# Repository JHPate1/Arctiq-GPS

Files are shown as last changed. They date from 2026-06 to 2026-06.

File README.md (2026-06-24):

GPS Banner
# Arctiq-GPS
A mainboard PCB design for my custom handheld navigation device.
(first time making a PCB and it all looks good so far!)

## What does it do?
This might seem vague if you don't know much about the project, so I'll try to explain everything here, along with who I am and my background.
PCB Image
## Who I am
I'm Jyot Patel, a 14-year-old living in the United States. I recently moved from Canada, where I was raised my entire life (born in India though). I like tinkering and making software projects in my free time, though I never really used GitHub that often. Git CLI just wasn't for me.

## What is this project?
This is the core foundation of my handheld device. It contains the power circuitry and the main GPS module that handles everything. At the heart of it sits an RPI CM4 module, which controls everything and runs the main OS I plan on flashing to the SD card.

## Why did I take on such an ambitious project for my first PCB?
Honestly, it was kind of a bad idea for a first PCB, but I do have experience with real hardware. It was more of a motivational thing: when you want to give up, you realize how much you've already put into the project, and that pushes you to keep going. This was my 4th revision of the board, so as you can see, it took me a while to get here.

## The routing looks ugly
I can admit the routing is terrible, but I checked it for the specific purpose and this will work just fine. I wasn't planning on making a Mona Lisa on a PCB. I just needed a functional board that won't explode after 3 years.

## Known Errors

Any DRC or ERC errors are left on purpose, KiCad was being a pain in the butt during import and export. I couldn't connect some traces, and there are a few schematic/footprint mixups. Take the PCB as the source of truth only!!!
If you spot anything else, feel free to open an issue.

### Special Thanks!
Special thanks to Hack Club Stardance for motivating me on this project. Without your help, I wouldn't have done it!

Thanks to https://github.com/ShawnHymel/rpi-cm4-carrier-template for providing me with the CM4 Carrier template!

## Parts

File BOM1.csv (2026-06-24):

# | Designator | Footprint | Qty | Designation | Recommended Spec | Digi-Key Part # | Unit Price | Ext Price
1 | C1 | C_0603_1608Metric | 1 | 4.7µF | 4.7µF, X5R/X7R, ≥10V | Search Caps | $0.05 | $0.05
2 | C2 | C_0603_1608Metric | 1 | 22µF | 22µF, X5R/X7R, ≥10V | Search Caps | $0.05 | $0.05
3 | C3, C6, C19, C21, C22 | C_0603_1608Metric | 5 | 100nF | 100nF, X7R, ≥10V | Search Caps | $0.05 | $0.25
4 | C4 | C_0603_1608Metric | 1 | 10µF | 10µF, X5R/X7R, ≥6.3V | Search Caps | $0.05 | $0.05
5 | C5 | C_0603_1608Metric | 1 | 33pF | 33pF, C0G/NP0, ≥25V | Search Caps | $0.05 | $0.05
6 | C7 | C_0603_1608Metric | 1 | 10µF | 10µF, X5R/X7R, ≥6.3V | Search Caps | $0.05 | $0.05
7 | C8 | C_0603_1608Metric | 1 | 20µF | 20µF, X5R/X7R, ≥6.3V | Search Caps | $0.05 | $0.05
8 | C9 | C_0603_1608Metric | 1 | 1µF | 1µF, X7R, ≥10V | Search Caps | $0.05 | $0.05
9 | C10, C15, C17 | C_0603_1608Metric | 3 | 10µF | 10µF, X5R/X7R, ≥6.3V | Search Caps | $0.05 | $0.15
10 | C11, C12, C32, C33, C35, C36, C37 | C_0805_2012Metric | 7 | 22µF | 22µF, X5R/X7R, ≥10V | Search Caps | $0.05 | $0.35
11 | C13, C14, C16, C25, C31 | C_0603_1608Metric | 5 | 0.1µF | 0.1µF, X7R, ≥16V | Search Caps | $0.05 | $0.25
12 | C18 | C_0603_1608Metric | 1 | 1.0µF | 1.0µF, X7R, ≥6.3V | Search Caps | $0.05 | $0.05
13 | C20 | C_0603_1608Metric | 1 | 47µF | 47µF, X5R/X7R, ≥6.3V min; 10V preferred | Search Caps | $0.05 | $0.05
14 | C23 | C_0603_1608Metric | 1 | 10nF | 10nF, C0G/NP0, ≥25V | Search Caps | $0.05 | $0.05
15 | C24 | C_0603_1608Metric | 1 | 10pF | 10pF, C0G/NP0, ≥25V | Search Caps | $0.05 | $0.05
16 | C26 | C_0603_1608Metric | 1 | 22µF | 22µF, X5R/X7R, ≥6.3V | Search Caps | $0.05 | $0.05
17 | C27 | C_0603_1608Metric | 1 | 2.2µF | 2.2µF, X7R, ≥10V | Search Caps | $0.05 | $0.05
18 | C28 | C_0805_2012Metric | 1 | 68nF | 68nF, X7R, ≥10V | Search Caps | $0.05 | $0.05
19 | C29 | C_0603_1608Metric | 1 | 4.7nF | 4.7nF, X7R/C0G, ≥10V | Search Caps | $0.05 | $0.05
20 | C30 | C_0603_1608Metric | 1 | 47pF | 47pF, C0G/NP0, ≥25V | Search Caps | $0.05 | $0.05
21 | C34 | C_0603_1608Metric | 1 | 47µF | 47µF, X5R/X7R, ≥6.3V min; 10V preferred | Search Caps | $0.05 | $0.05
22 | D1 | LED_0402_1005Metric | 1 | LED |  | Search LEDs | $0.15 | $0.15
23 | D2 | LED_0402_1005Metric | 1 | DEBUG |  | Search LEDs | $0.15 | $0.15
24 | J1 | USB_C_Receptacle_GCT_USB4085 | 1 | USB-C Receptacle |  | 2073-USB4085-GF-ACT-ND | $0.89 | $0.89
25 | J2 | SolderWire-0.127sqmm_1x02_P3.7mm | 1 | Conn_01x02_Socket |  | Search Connectors | $0.50 | $0.50
26 | J3 | U.FL_Hirose_U.FL-R-SMT-1_Vertical | 1 | U.FL Coaxial Connector |  | H11891CT-ND | $1.29 | $1.29
27 | J4 | microSD_HC_Wuerth_693072010801 | 1 | microSD Card Holder |  | 732-693072010801-1-ND | $3.41 | $3.41
28 | J5 | JST_NV_B04P-NV_1x04_P5.00mm_Vertical | 1 | Conn_01x04_Socket |  | Search Connectors | $0.50 | $0.50
29 | J6 | CON_522711569_MOL | 1 | 522711569 |  | Search Connectors | $0.50 | $0.50
30 | J7 | PinHeader_1x02_P2.54mm_Vertical | 1 | 01x02 Pin Header |  | Search Connectors | $0.50 | $0.50
31 | L1 | L_1210_3225Metric | 1 | 1.5µH | 1.5µH shielded power inductor, Isat ≥12A, low DCR | Search Inductors | $0.80 | $0.80
32 | L2 | L_0402_1005Metric | 1 | 27nH | 27nH RF inductor/matching part | Search Inductors | $0.80 | $0.80
33 | L3 | L_0402_1005Metric | 1 | 1µH | 1µH power inductor, Isat ≥6A (0402 unsuitable for BQ25895 power stage) | Search Inductors | $0.80 | $0.80
34 | L4 | L_0603_1608Metric | 1 | 2.2µH | 2.2µH shielded power inductor, Isat ≥3A, low DCR | Search Inductors | $0.80 | $0.80
35 | MK1 | Knowles_SPH0645LM4H-6_3.5x2.65mm | 1 | SPH0645LM4H | MEMS Microphone | 6017-SPH0645LM4H-BCT-ND | $3.44 | $3.44
36 | Module1 | Raspberry-Pi-4-Compute-Module | 1 | CM4 Compute Module | Raspberry Pi Compute Module 4 (SC0667) | 2648-SC0667-ND | $63.23 | $63.23
37 | R1, R2 | R_0603_1608Metric | 2 | 5.1k |  | Search Resistors | $0.01 | $0.02
38 | R3, R10, R23 | R_0603_1608Metric | 3 | 10K |  | Search Resistors | $0.01 | $0.03
39 | R4 | R_0603_1608Metric | 1 | 200 | ILIM resistor | Search Resistors | $0.01 | $0.01
40 | R5 | R_0603_1608Metric | 1 | 10kΩ |  | Search Resistors | $0.01 | $0.01
41 | R6 | R_0603_1608Metric | 1 | 12K 1% |  | Search Resistors | $0.01 | $0.01
42 | R7, R8, R21, R22 | R_0603_1608Metric | 4 | 4.7k |  | Search Resistors | $0.01 | $0.04
43 | R9, R14, R15 | R_0603_1608Metric | 3 | 10k |  | Search Resistors | $0.01 | $0.03
44 | R11, R24, R27, R28 | R_0603_1608Metric | 4 | 100k |  | Search Resistors | $0.01 | $0.04
45 | R12, R17, R25 | R_0603_1608Metric | 3 | 100K |  | Search Resistors | $0.01 | $0.03
46 | R13 | R_0603_1608Metric | 1 | 2.2k |  | Search Resistors | $0.01 | $0.01
47 | R16 | R_0603_1608Metric | 1 | 100 |  | Search Resistors | $0.01 | $0.01
48 | R18 | R_0603_1608Metric | 1 | 15k |  | Search Resistors | $0.01 | $0.01
49 | R19 | R_0603_1608Metric | 1 | 1K |  | Search Resistors | $0.01 | $0.01
50 | R20 | R_0603_1608Metric | 1 | 316k |  | Search Resistors | $0.01 | $0.01
51 | R26 | R_0603_1608Metric | 1 | 453k |  | Search Resistors | $0.01 | $0.01
52 | SW2 | Panasonic_EVQPUJ_EVQPUA | 1 | Push Button Switch | Shielded tactile switch | P8029SCT-ND | $0.60 | $0.60
53 | TH1 | R_0201_0603Metric | 1 | 10K | Thermistor | Search Resistors | $0.01 | $0.01
54 | U1 | Texas_RTW_WQFN-24-1EP_4x4mm | 1 | BQ25895RTW | Battery Buck-Boost Charger | 296-44345-1-ND | $3.29 | $3.29
55 | U2 | ublox_NEO | 1 | NEO-M9N | GNSS Receiver Module | 672-NEO-M9N-00B-ND | $14.69 | $14.69
56 | U3 | TSOT-23-5_RIT | 1 | RT9742GGJ5 | Power Load Switch | 1028-1436-1-ND | $0.92 | $0.92
57 | U4 | DRL0006A | 1 | TPS6282533DMQR | Buck Converter 3.3V 2A | 296-TPS6282533DMQRCT-ND | $1.25 | $1.25
58 | U5 | TQFN-16-1EP_3x3mm | 1 | MAX98357A | Class D Audio Amplifier | MAX98357AETE+TCT-ND | $3.73 | $3.73
59 | U6 | SOT-23-6 | 1 | USBLC6-2SC6 | USB ESD Protection | 497-11882-1-ND | $0.67 | $0.67
60 | U7 | 21-0168E_T822-3_MXM | 1 | MAX17048G+T10 | Fuel Gauge IC | MAX17048G+T10CT-ND | $3.62 | $3.62
61 | U8 | RHL0020A | 1 | TPS61088RHLR | Boost Converter 10A | 296-42129-1-ND | $2.74 | $2.74
62 | U9 | 21-0114C_MXM | 1 | MAX16054AZT+ | Pushbutton On/Off Controller | MAX16054AZT+TCT-ND | $3.71 | $3.71
63 | NOB | 4 PIN POGO MAG | 1 | 4-Pin Pogo Magnetic Connector |  | Amazon: B0GJPCX49H | $9.99 | $9.99
64 | NOB | 5 INCH DISPLAY, CAPACITIVE TOUCH, DSI | 1 | 5" DSI Capacitive Touch Display | Waveshare 800×480 | Amazon: B08H23KB1G | $46.00 | $46.00
65 | NOB | Active GNSS ANT | 1 | Active GNSS Antenna |  | AliExpress | $8.00 | $8.00
66 | NOB | 5000MAH Battery | 2 | 5000mAh LiPo Battery | 3.7V with JST PH2.0 connector | Amazon: B0GL1MH5YT | $13.00 | $26.00
67 | NOB | 128GB SD | 1 | 128GB microSD Card | Kingston Canvas Select Plus | Amazon: B0FCZTYSN6 | $23.99 | $23.99
68 | NOB | ABS/RESIN ENCLOSURE | 1 | ABS/Resin Enclosure | Custom enclosure | PCBWAY (custom) | $25.00 | $25.00
69 | NOB | SPEAKER | 1 | Speaker |  | AliExpress | $5.00 | $5.00
70 | NOB | PCB + SHIPPING | 1 | PCB Fabrication & Shipping | PCB fabrication + component shipping | PCBWAY | $75.00 | $75.00
 |  | TOTAL | 100 |  |  |  |  | $334.10

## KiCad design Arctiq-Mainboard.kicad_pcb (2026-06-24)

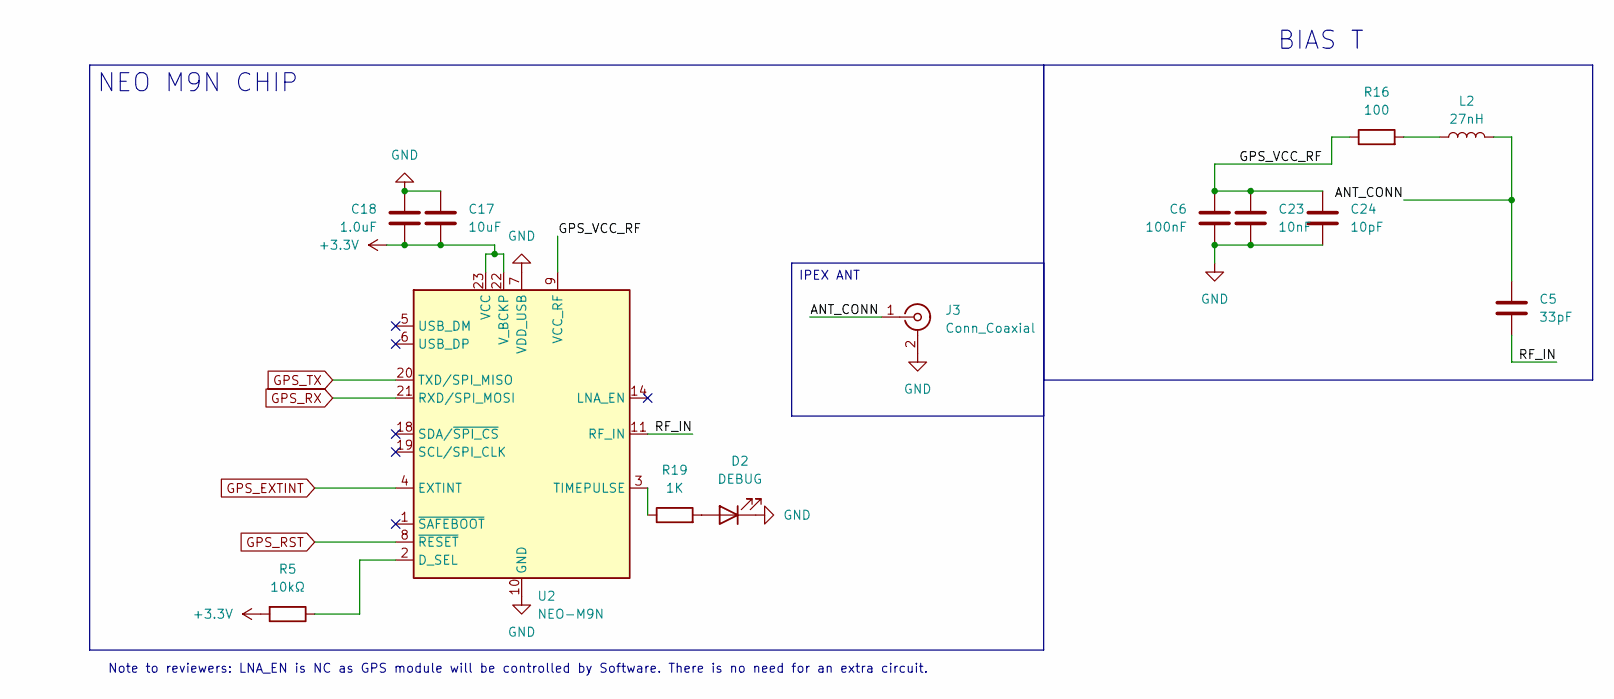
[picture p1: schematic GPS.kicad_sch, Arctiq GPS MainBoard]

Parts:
C5: 33pF; C_0603_1608Metric
C6: 100nF; C_0603_1608Metric
C17: 10uF; C_0603_1608Metric
C18: 1.0uF; C_0603_1608Metric
C23: 10nF; C_0603_1608Metric
C24: 10pF; C_0603_1608Metric
D2: DEBUG; LED_0402_1005Metric
J3: Conn_Coaxial; U.FL_Hirose_U.FL-R-SMT-1_Vertical
L2: 27nH; L_0402_1005Metric
R5: 10kΩ; R_0603_1608Metric
R16: 100; R_0603_1608Metric
R19: 1K; R_0603_1608Metric
U2: NEO-M9N; ublox_NEO

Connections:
+3.3V: C17.2, C18.2, R5.2, U2.22 (V_BCKP), U2.23 (VCC); also elsewhere on the board
/GPS Module/ANT_CONN: C5.2, J3.1 (In), L2.2
/GPS Module/GPS_VCC_RF: C6.2, C23.2, C24.2, R16.1, U2.9 (VCC_RF)
/GPS Module/RF_IN: C5.1, U2.11 (RF_IN)
GPS_EXTINT: U2.4 (EXTINT); also elsewhere on the board
GPS_RST: U2.8 (~RESET); also elsewhere on the board
GPS_RX: U2.21 (RXD/SPI_MOSI); also elsewhere on the board
GPS_TX: U2.20 (TXD/SPI_MISO); also elsewhere on the board
unnamed: D2.2 (A), R19.2
unnamed: L2.1, R16.2
unnamed: R5.1, U2.2 (D_SEL)
unnamed: R19.1, U2.3 (TIMEPULSE)

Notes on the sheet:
Note to reviewers: LNA_EN is NC as GPS module will be controlled by Software. There is no need for an extra circuit.
BIAS T
IPEX ANT
NEO M9N CHIP

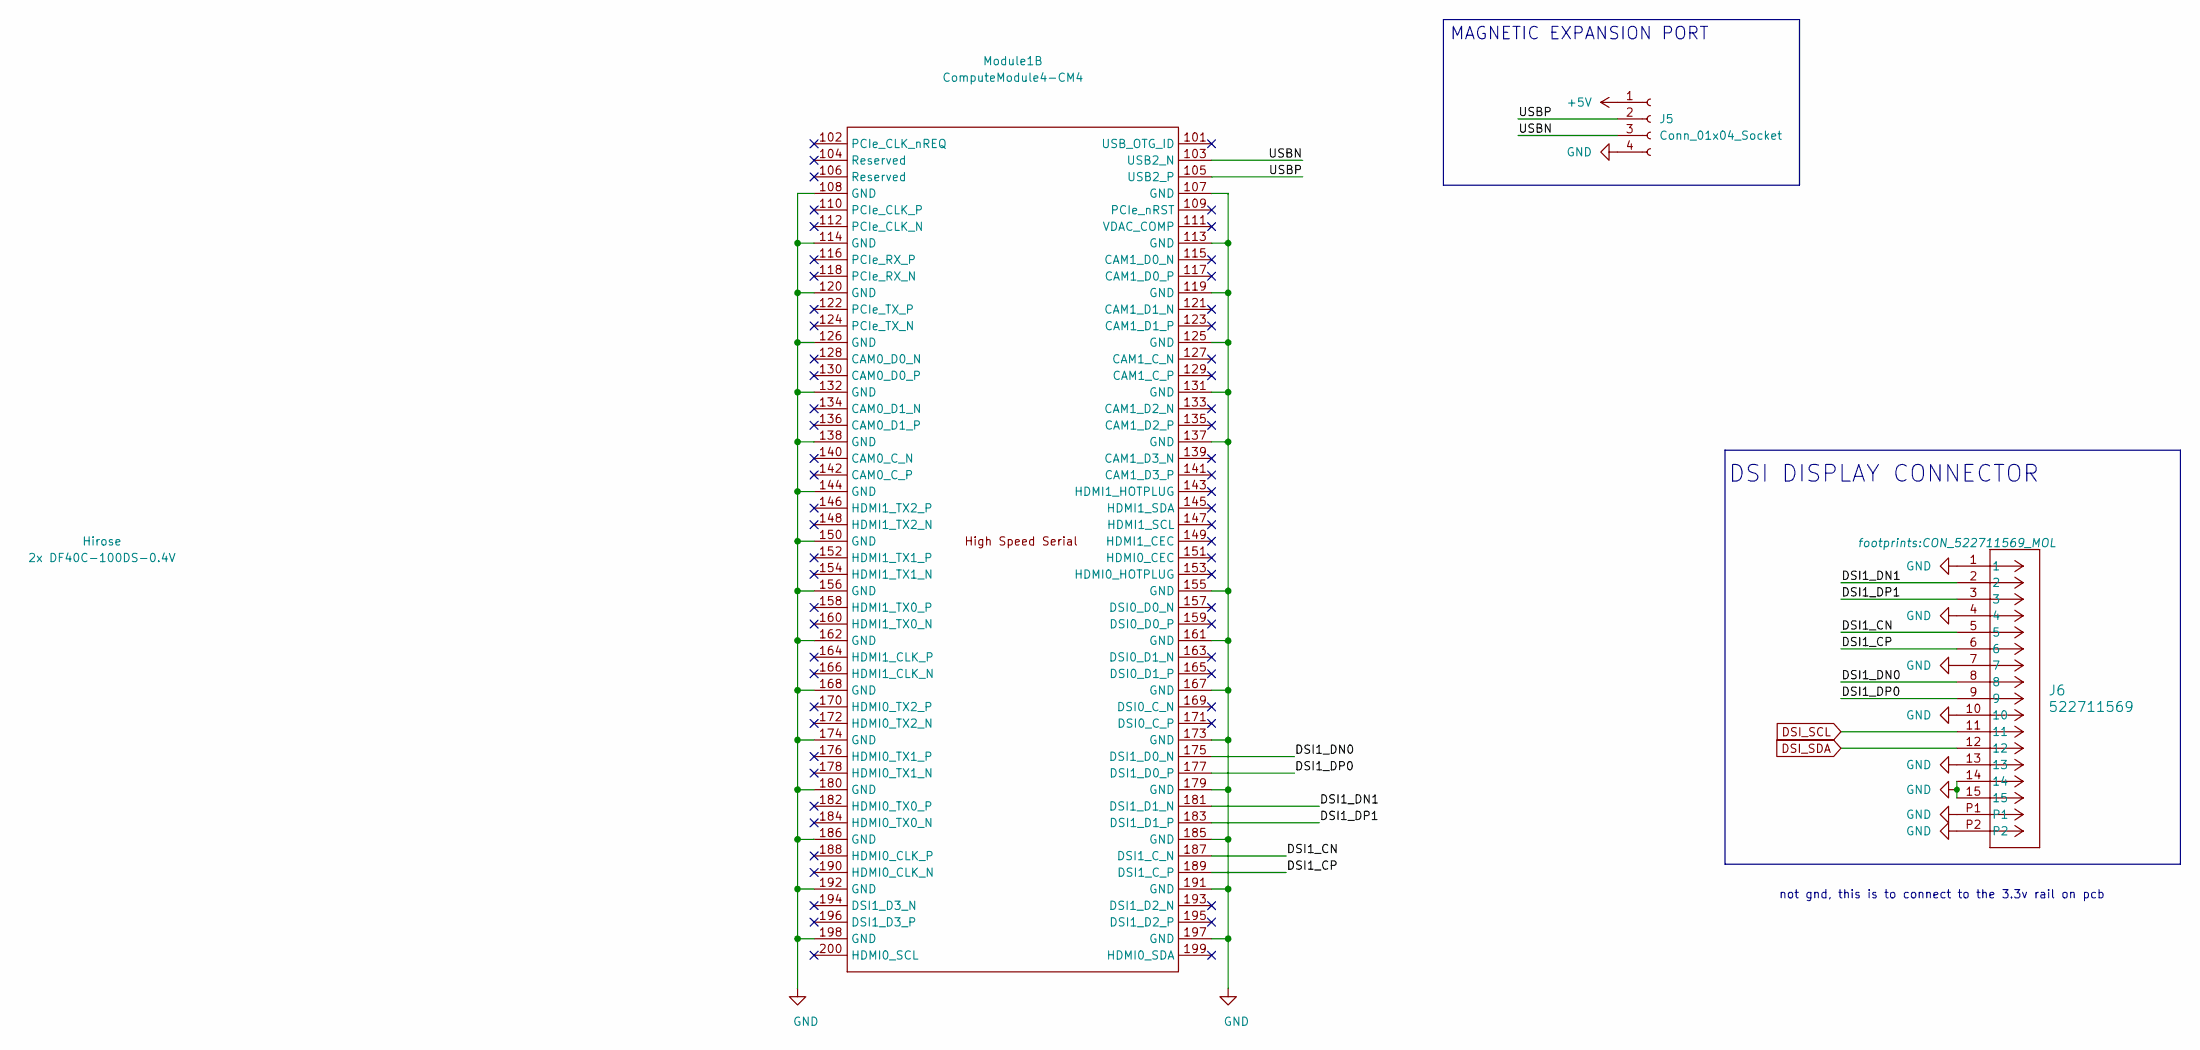
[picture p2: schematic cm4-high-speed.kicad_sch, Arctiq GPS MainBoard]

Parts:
J5: Conn_01x04_Socket; JST_NV_B04P-NV_1x04_P5.00mm_Vertical
J6: 522711569; CON_522711569_MOL
Module1: ComputeModule4-CM4; CONN100_DF40C-100DP-0.4V51_HIR; MPN 2x DF40C-100DS-0.4V; Digi-Key_PN 2x H11615CT-ND

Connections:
+5V: J5.1; also elsewhere on the board
/CM4 High Speed/DSI1_CN: J6.5, Module1.187 (DSI1_C_N)
/CM4 High Speed/DSI1_CP: J6.6, Module1.189 (DSI1_C_P)
/CM4 High Speed/DSI1_DN0: J6.8, Module1.175 (DSI1_D0_N)
/CM4 High Speed/DSI1_DN1: J6.2, Module1.181 (DSI1_D1_N)
/CM4 High Speed/DSI1_DP0: J6.9, Module1.177 (DSI1_D0_P)
/CM4 High Speed/DSI1_DP1: J6.3, Module1.183 (DSI1_D1_P)
/CM4 High Speed/USBN: J5.3, Module1.103 (USB2_N)
/CM4 High Speed/USBP: J5.2, Module1.105 (USB2_P)
DSI_SCL: J6.11; also elsewhere on the board
DSI_SDA: J6.12; also elsewhere on the board

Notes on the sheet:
not gnd, this is to connect to the 3.3v rail on pcb
DSI DISPLAY CONNECTOR
MAGNETIC EXPANSION PORT

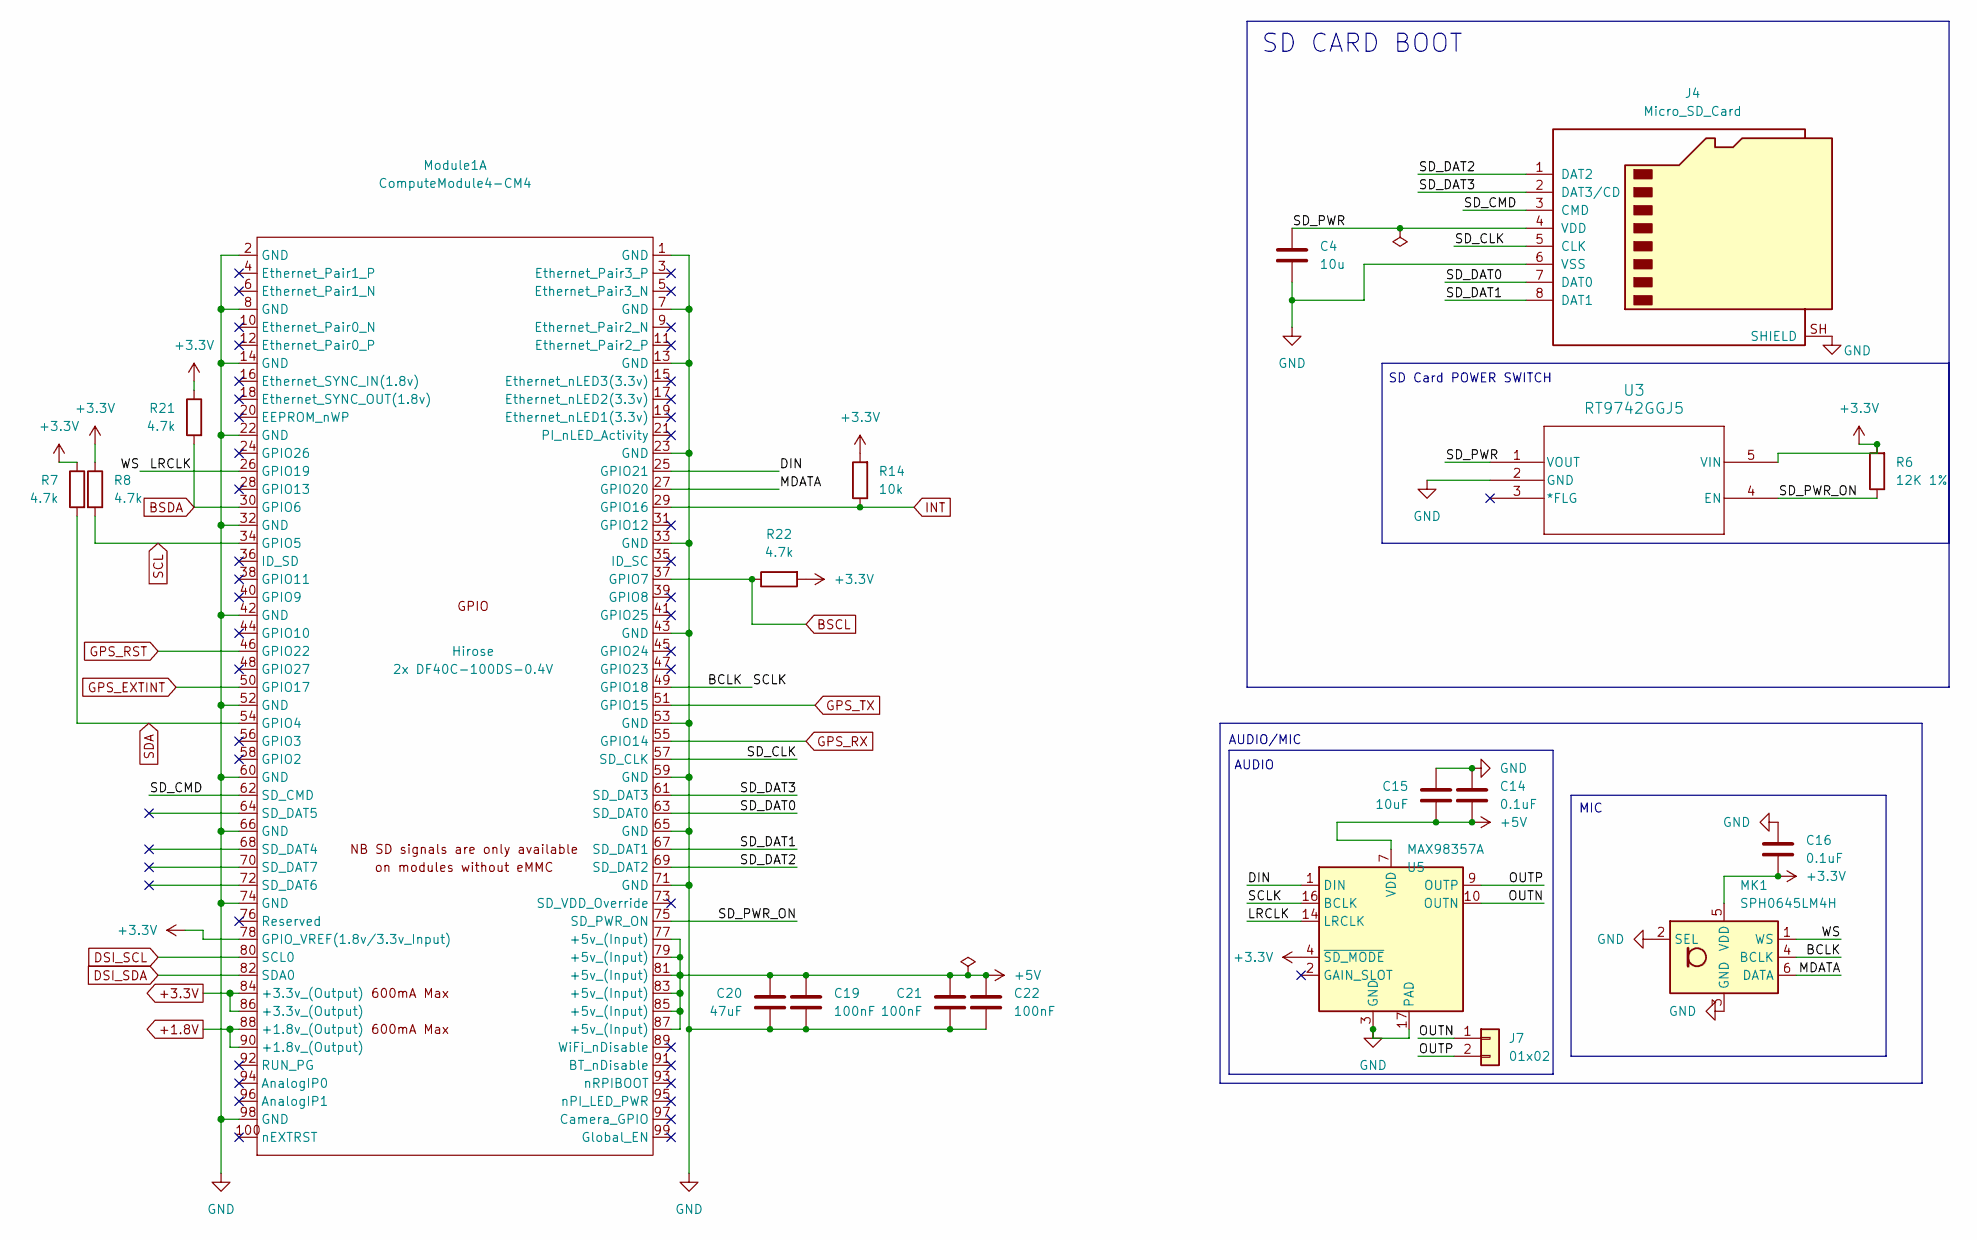
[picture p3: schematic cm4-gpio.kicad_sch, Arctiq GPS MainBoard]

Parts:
C4: 10u; C_0603_1608Metric
C14, C16: 0.1uF; C_0603_1608Metric
C15: 10uF; C_0603_1608Metric
C19, C21, C22: 100nF; C_0603_1608Metric
C20: 47uF; C_0603_1608Metric
J4: Micro_SD_Card; microSD_HC_Wuerth_693072010801
J7: 01x02; PinHeader_1x02_P2.54mm_Vertical
MK1: SPH0645LM4H; Knowles_SPH0645LM4H-6_3.5x2.65mm
Module1: ComputeModule4-CM4; CONN100_DF40C-100DP-0.4V51_HIR; MPN 2x DF40C-100DS-0.4V; Digi-Key_PN 2x H11615CT-ND
R6: 12K 1%; R_0603_1608Metric
R7, R8, R21, R22: 4.7k; R_0603_1608Metric
R14: 10k; R_0603_1608Metric
U3: RT9742GGJ5; TSOT-23-5_RIT
U5: MAX98357A; TQFN-16-1EP_3x3mm_P0.5mm_EP1.23x1.23mm

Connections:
+1.8V: Module1.88 (+1.8v_(Output)), Module1.90 (+1.8v_(Output))
+3.3V: C16.2, MK1.5 (VDD), Module1.78 (GPIO_VREF(1.8v/3.3v_Input)), Module1.84 (+3.3v_(Output)), Module1.86 (+3.3v_(Output)), R6.2, R7.1, R8.1, R14.2, R21.1, R22.2, U3.5 (VIN), U5.4 (~SD_MODE); also elsewhere on the board
+5V: C14.2, C15.2, C19.1, C20.2, C21.2, C22.1, Module1.77 (+5v_(Input)), Module1.79 (+5v_(Input)), Module1.81 (+5v_(Input)), Module1.83 (+5v_(Input)), Module1.85 (+5v_(Input)), Module1.87 (+5v_(Input)), U5.7 (VDD), U5.8 (VDD); also elsewhere on the board
/CM4 GPIO/BCLK: MK1.4 (BCLK), Module1.49 (GPIO18), U5.16 (BCLK)
/CM4 GPIO/DIN: Module1.25 (GPIO21), U5.1 (DIN)
/CM4 GPIO/LRCLK: MK1.1 (WS), Module1.26 (GPIO19), U5.14 (LRCLK)
/CM4 GPIO/MDATA: MK1.6 (DATA), Module1.27 (GPIO20)
/CM4 GPIO/OUTN: J7.1, U5.10 (OUTN)
/CM4 GPIO/OUTP: J7.2, U5.9 (OUTP)
/CM4 GPIO/SD_CLK: J4.5 (CLK), Module1.57 (SD_CLK)
/CM4 GPIO/SD_CMD: J4.3 (CMD), Module1.62 (SD_CMD)
/CM4 GPIO/SD_DAT0: J4.7 (DAT0), Module1.63 (SD_DAT0)
/CM4 GPIO/SD_DAT1: J4.8 (DAT1), Module1.67 (SD_DAT1)
/CM4 GPIO/SD_DAT2: J4.1 (DAT2), Module1.69 (SD_DAT2)
/CM4 GPIO/SD_DAT3: J4.2 (DAT3/CD), Module1.61 (SD_DAT3)
/CM4 GPIO/SD_PWR: C4.1, J4.4 (VDD), U3.1 (VOUT)
/CM4 GPIO/SD_PWR_ON: Module1.75 (SD_PWR_ON), R6.1, U3.4 (EN)
BSCL: Module1.37 (GPIO7), R22.1; also elsewhere on the board
BSDA: Module1.30 (GPIO6), R21.2; also elsewhere on the board
DSI_SCL: Module1.80 (SCL0); also elsewhere on the board
DSI_SDA: Module1.82 (SDA0); also elsewhere on the board
GPS_EXTINT: Module1.50 (GPIO17); also elsewhere on the board
GPS_RST: Module1.46 (GPIO22); also elsewhere on the board
GPS_RX: Module1.55 (GPIO14); also elsewhere on the board
GPS_TX: Module1.51 (GPIO15); also elsewhere on the board
INT: Module1.29 (GPIO16), R14.1; also elsewhere on the board
SCL: Module1.34 (GPIO5), R8.2; also elsewhere on the board
SDA: Module1.54 (GPIO4), R7.2; also elsewhere on the board

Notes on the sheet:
AUDIO
MIC
SD CARD BOOT
AUDIO/MIC
SD Card POWER SWITCH

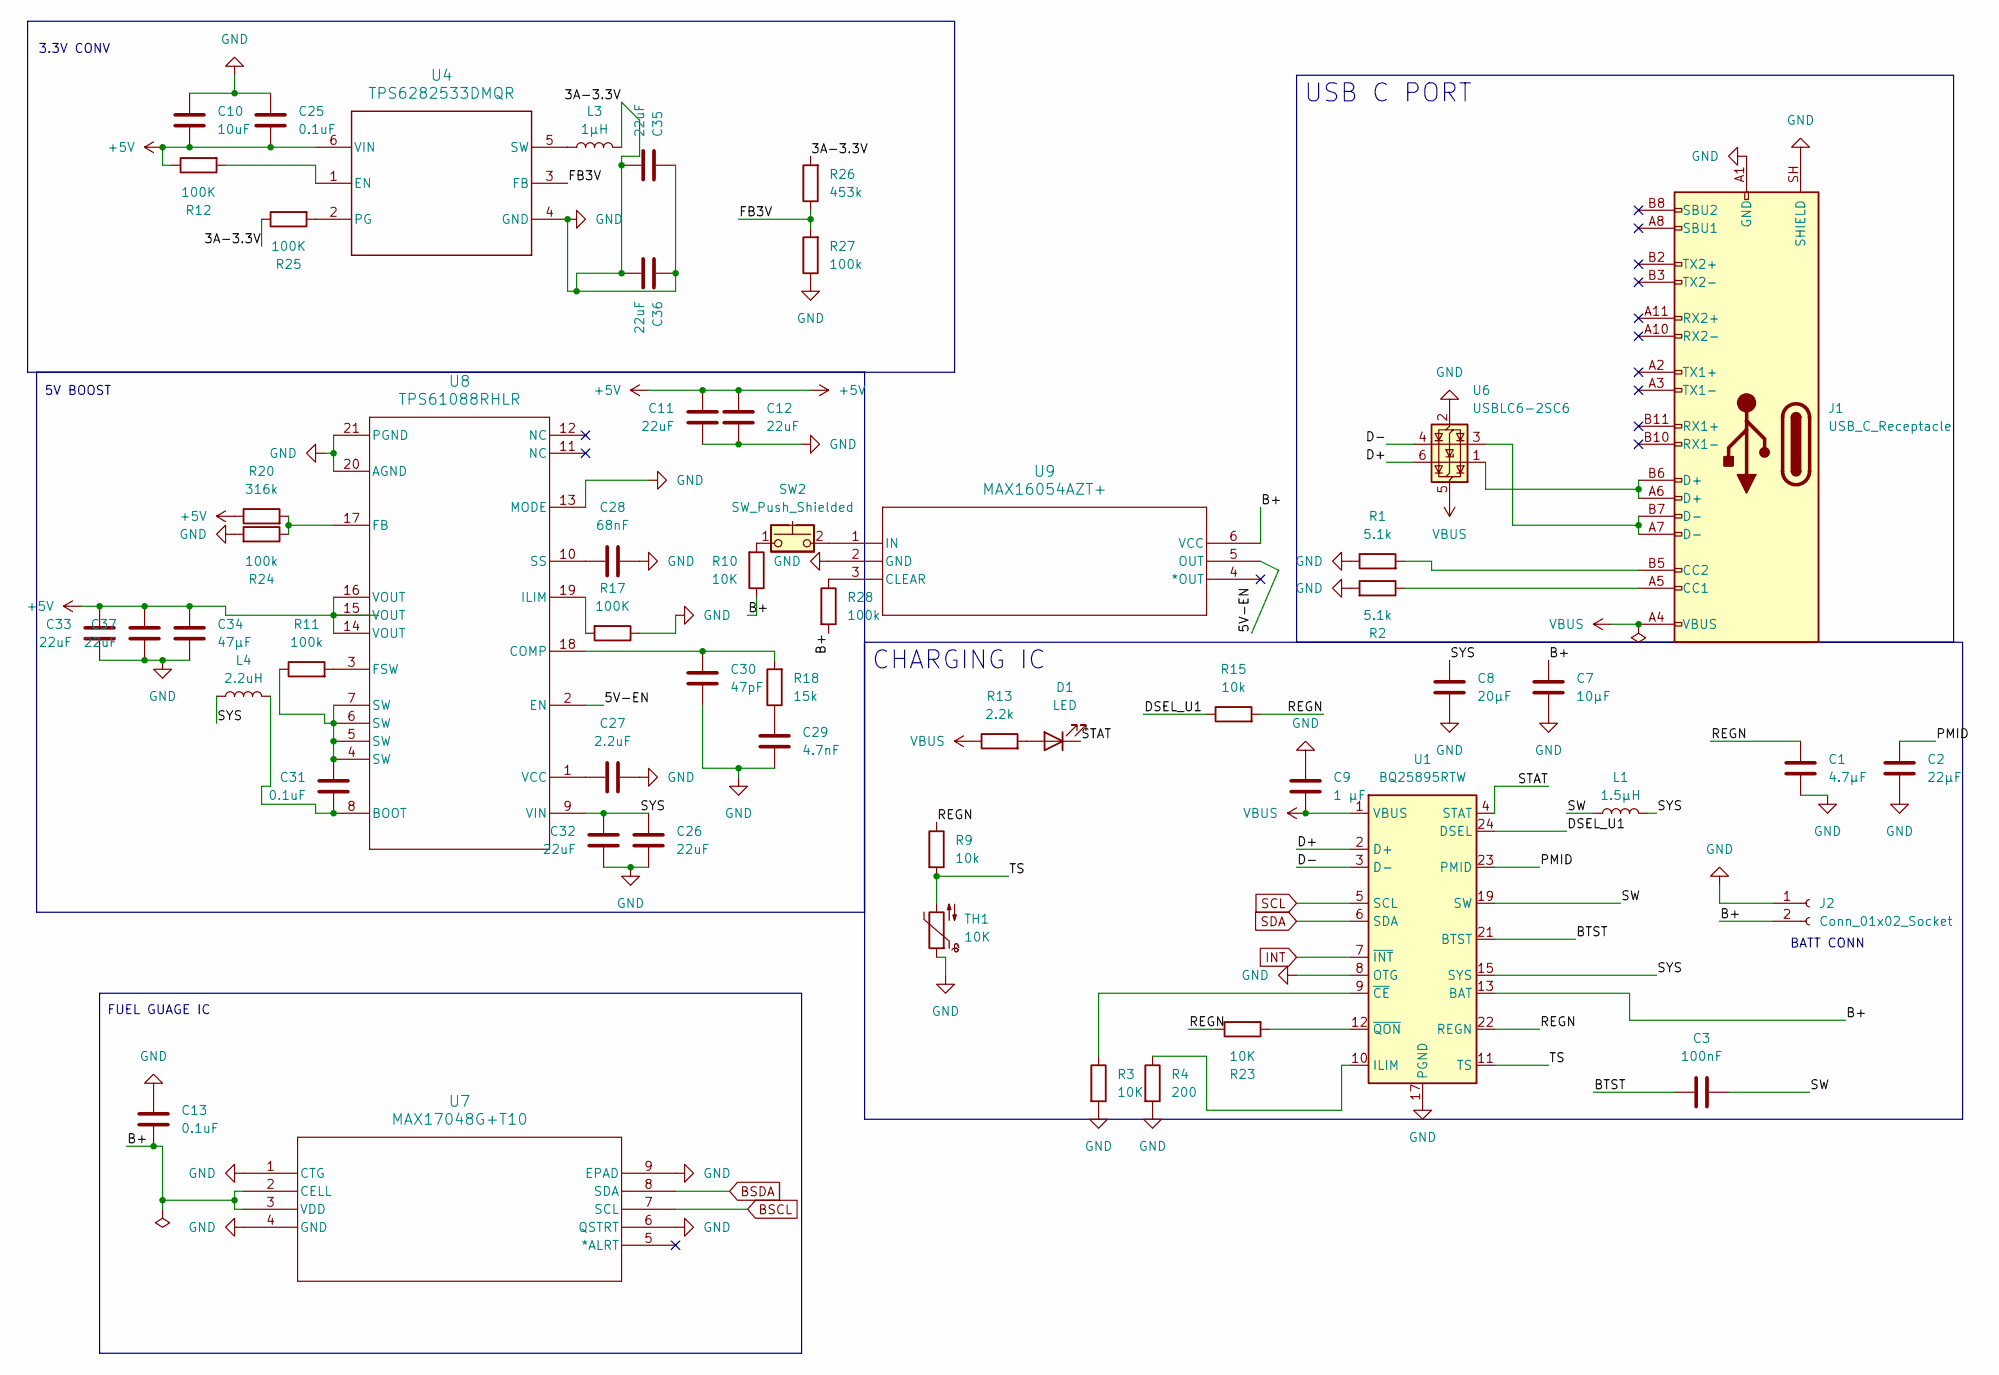
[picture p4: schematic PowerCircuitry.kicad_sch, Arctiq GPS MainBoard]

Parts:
C1: 4.7µF; C_0603_1608Metric
C2: 22µF; C_0603_1608Metric
C3: 100nF; C_0603_1608Metric
C7: 10µF; C_0603_1608Metric
C8: 20µF; C_0603_1608Metric
C9: 1 µF; C_0603_1608Metric
C10: 10uF; C_0603_1608Metric
C11, C12, C32, C33, C35, C36, C37: 22uF; C_0805_2012Metric
C13, C25, C31: 0.1uF; C_0603_1608Metric
C26: 22uF; C_0603_1608Metric
C27: 2.2uF; C_0603_1608Metric
C28: 68nF; C_0805_2012Metric
C29: 4.7nF; C_0603_1608Metric
C30: 47pF; C_0603_1608Metric
C34: 47µF; C_0603_1608Metric
D1: LED; LED_0402_1005Metric
J1: USB_C_Receptacle; USB_C_Receptacle_GCT_USB4085
J2: Conn_01x02_Socket; SolderWire-0.127sqmm_1x02_P3.7mm_D0.48mm_OD1mm
L1: 1.5µH; L_1210_3225Metric
L3: 1µH; L_0402_1005Metric
L4: 2.2uH; L_0603_1608Metric
R1, R2: 5.1k; R_0603_1608Metric
R3, R10, R23: 10K; R_0603_1608Metric
R4: 200; R_0603_1608Metric
R9, R15: 10k; R_0603_1608Metric
R11, R24, R27, R28: 100k; R_0603_1608Metric
R12, R17, R25: 100K; R_0603_1608Metric
R13: 2.2k; R_0603_1608Metric
R18: 15k; R_0603_1608Metric
R20: 316k; R_0603_1608Metric
R26: 453k; R_0603_1608Metric
SW2: SW_Push_Shielded; Panasonic_EVQPUJ_EVQPUA
TH1: 10K; R_0201_0603Metric
U1: BQ25895RTW; Texas_RTW_WQFN-24-1EP_4x4mm_P0.5mm_EP2.7x2.7mm_ThermalVias
U4: TPS6282533DMQR; DRL0006A
U6: USBLC6-2SC6; SOT-23-6
U7: MAX17048G+T10; 21-0168E_T822-3_MXM
U8: TPS61088RHLR; RHL0020A
U9: MAX16054AZT+; 21-0114C_MXM

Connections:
+5V: C10.2, C11.1, C12.1, C25.2, C33.2, C34.1, C37.2, R12.1, R20.1, U4.6 (VIN), U8.14 (VOUT), U8.15 (VOUT), U8.16 (VOUT); also elsewhere on the board
/Power Circuitry/5V-EN: U8.2 (EN), U9.5 (OUT)
/Power Circuitry/B+: C7.2, C13.2, J2.2, R10.1, R28.2, U1.13 (BAT), U1.14 (BAT), U7.2 (CELL), U7.3 (VDD), U9.6 (VCC)
/Power Circuitry/BTST: C3.2, U1.21 (BTST)
/Power Circuitry/D+: U1.2 (D+), U6.6 (I/O1)
/Power Circuitry/D-: U1.3 (D-), U6.4 (I/O2)
/Power Circuitry/DSEL_U1: R15.1, U1.24 (DSEL)
/Power Circuitry/FB3V: R26.1, R27.2, U4.3 (FB)
/Power Circuitry/PMID: C2.1, U1.23 (PMID)
/Power Circuitry/REGN: C1.2, R9.1, R15.2, R23.1, U1.22 (REGN)
/Power Circuitry/STAT: D1.1 (K), U1.4 (STAT)
/Power Circuitry/SW: C3.1, L1.1, U1.19 (SW), U1.20 (SW)
/Power Circuitry/SYS: C8.2, C26.1, C32.2, L1.2, L4.1, U1.15 (SYS), U1.16 (SYS), U8.9 (VIN)
/Power Circuitry/TS: R9.2, TH1.2, U1.11 (TS)
BSCL: U7.7 (SCL); also elsewhere on the board
BSDA: U7.8 (SDA); also elsewhere on the board
INT: U1.7 (~INT); also elsewhere on the board
unnamed: C29.1, R18.1
unnamed: C31.1, R11.1, U8.4 (SW), U8.5 (SW), U8.6 (SW), U8.7 (SW)
unnamed: D1.2 (A), R13.2
unnamed: J1.A5 (CC1), R2.1
unnamed: J1.B5 (CC2), R1.2
unnamed: J1.A6 (D+), J1.B6 (D+), U6.1 (I/O1)
unnamed: J1.A7 (D-), J1.B7 (D-), U6.3 (I/O2)
unnamed: R10.2, SW2.1
unnamed: R4.1, U1.10 (ILIM)
unnamed: R3.1, U1.9 (~CE)
unnamed: R23.2, U1.12 (~QON)
unnamed: R12.2, U4.1 (EN)
unnamed: R25.2, U4.2 (PG)
unnamed: L3.1, U4.5 (SW)
unnamed: C31.2, L4.2, U8.8 (BOOT)
unnamed: C30.1, R18.2, U8.18 (COMP)
unnamed: R20.2, R24.1, U8.17 (FB)
unnamed: R11.2, U8.3 (FSW)
unnamed: R17.2, U8.19 (ILIM)
unnamed: C28.1, U8.10 (SS)
unnamed: C27.1, U8.1 (VCC)
unnamed: R28.1, U9.3 (CLEAR)
unnamed: SW2.2, U9.1 (IN)
SCL: U1.5 (SCL); also elsewhere on the board
SDA: U1.6 (SDA); also elsewhere on the board
VBUS: C9.2, J1.A4 (VBUS), J1.A9 (VBUS), J1.B4 (VBUS), J1.B9 (VBUS), R13.1, U1.1 (VBUS), U6.5 (VBUS)

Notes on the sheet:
FUEL GUAGE IC
5V BOOST
3.3V CONV
BATT CONN
USB C PORT
CHARGING IC

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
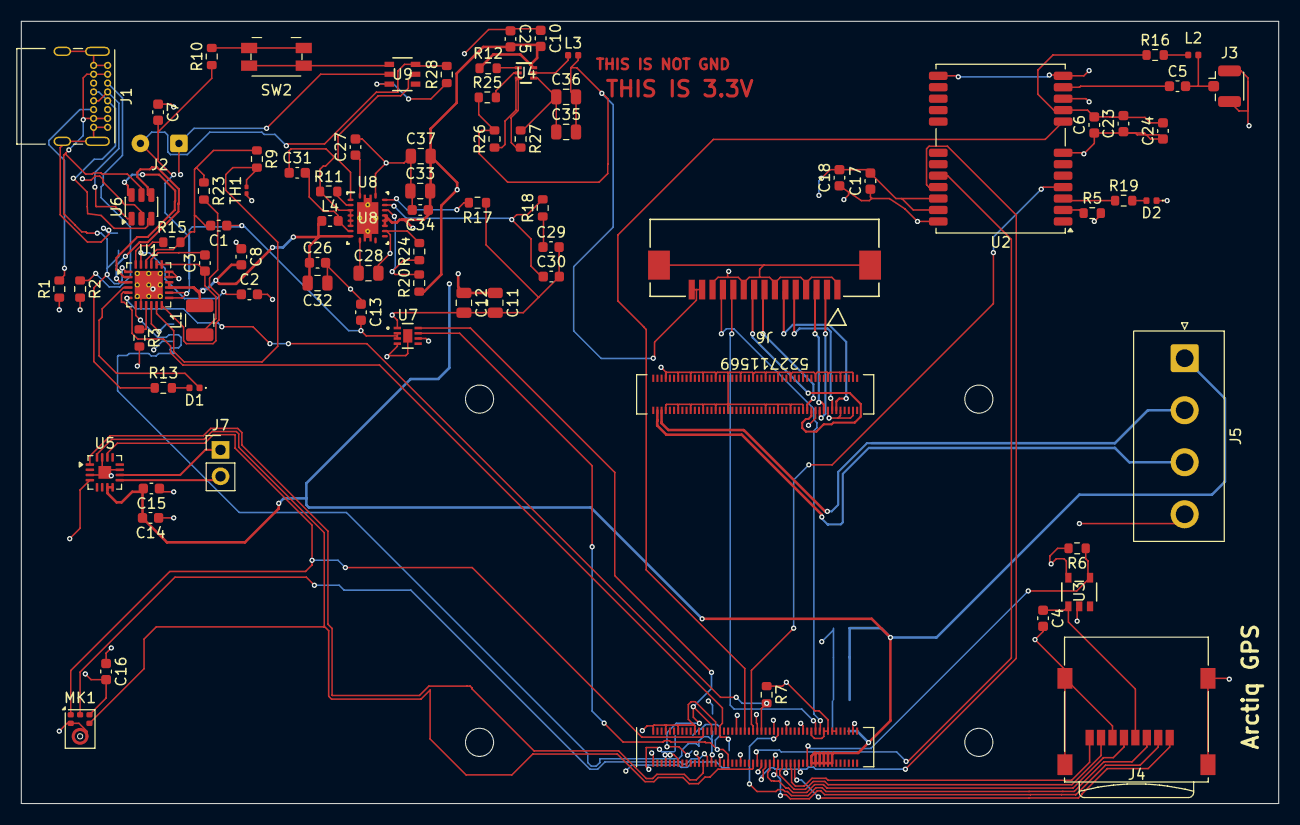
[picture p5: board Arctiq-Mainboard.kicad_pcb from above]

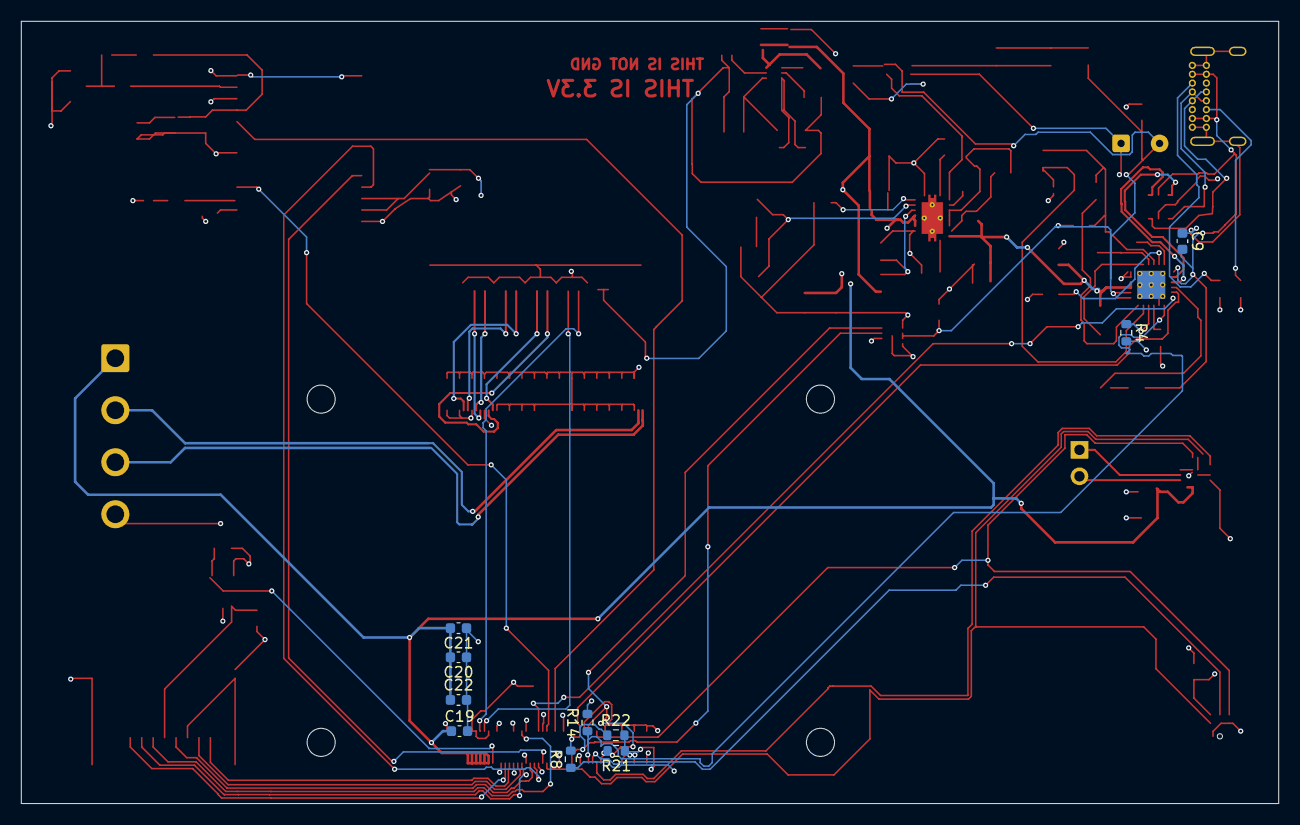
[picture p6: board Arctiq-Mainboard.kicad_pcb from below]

Board: 4 copper layers, 120.9 x 75.2 mm, 91 parts (10 on the bottom side), 81 nets.

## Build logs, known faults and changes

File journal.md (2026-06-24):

# Arctiq-GPS Journal

Time after timelapse crash:
### 19 hours
Time with total hours
### 21 hours

## Power, Storage, and a reference schematic that is actually just malware
Started the week routing the boost converter, fuel gauge and SD card. That was the plan anyway. Burned through approximately 87 reddit threads, 12 mutually contradictory application notes and 3 datasheets only to realise that the entire schematic was garbage. Not only did I transpose two resistor values, nobody anywhere ever mentions that none of the example component values work if your trace is longer than 2mm. Five hours completely wasted. Only win: I caught this before I ordered boards. That would have been a week waiting for a very expensive coaster.

Time: 5.2h

## RF, Audio, and the GPS module that hates me personally
Things marginally improved once I moved onto the Neo M9N, audio codec and mic amp. GPS ate almost all of this block. Nobody warns you that you can get everything else perfect and the entire board will still be useless because you routed the antenna trace 0.5mm too close to a ground via.

RF does not negotiate. RF does not care about your deadline. RF will brick your entire board for fun. I triple checked the 50 ohm impedance calculation four separate times. It is still probably wrong.

Time: 3.1h. 2.9 of that was staring at the impedance calculator.

## CM4 Layout Shuffle
Broke out most of the peripherals to the CM4 connector. 90% of this session was just dragging components around the screen going "where the F**K do I put this". Constantly alt-tabbing between schematic and PCB editor. This is the single worst habit you can have doing layout. I knew this. I did it anyway. By the end I had a rat's nest that looked like someone spilled spaghetti on the editor.
(editors note: this is funny as hell bro. i am criticizing my own work :rofl:)
Time: 1.4h. No net useful work accomplished.

## The Rush
Realised at 10pm that if I didn't finish this by the end of the week I was going to blow the project deadline. So I turned my brain off, and started smashing keys and traces together. 
Not the best idea but it did help, somewhat. (no it didnt. please lord i wasted like 8 hours fixing half of this work)

## The Reckoning
Hit save. Ran DRC.

517 errors. 319 warnings. I counted.

Every single one was clearance. I crammed everything so tight half the silkscreens and traces were practically touching. Spent the next two entire evenings just moving every component 1mm to the right. No new features. No improvements. Just damage control.

Time: 8.7h. I want that time back.

## Validation and Simulation
DRC is finally clean (NOT, well it is but like the errors are negligible). Ran SI sims on every high speed bus, checked power and ground plane impedance, went through every net one by one. For a first attempt at something this size it could be an awful lot worse.

Only real unforced error was the SD card traces which I routed all the way across the board for absolutely no reason. I knew that was wrong the second I finished routing them. Fixed it now. As far as I can tell, this board should actually boot. There is approximately a 95% chance this is correct.

So I proceeded to move half of the board around and move the sd card slot closer.

Addendum 1:12am: Just noticed I swapped TX and RX on the GPS. Fixed. God damnit.
another addendum 2:40am, god my parents are gonna kill me: I used BLIND VIAS for almost all power and GND traces. WHY DID NOBODY EDUCATE ME ON THE COST. Thankfully

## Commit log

2026-06-24 Fix PCB image link in README.md
2026-06-24 Document known errors in PCB design
    Added a section for known errors in the PCB design.
2026-06-24 Update journal with project time and issues
    Added new journal entries detailing time spent on project and issues encountered with the schematic.
